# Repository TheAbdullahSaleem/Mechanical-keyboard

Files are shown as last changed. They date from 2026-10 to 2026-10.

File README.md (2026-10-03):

# Mechanical KEEB!!! 
This is a keyboard completely made by me 



## HOW THIS WAS MADE
I made it from scratch compltely scratch and followed the keeb.hackclub guide for it

## How to install:
It is not installable how ever you can see the 3d model at https://cad.onshape.com/documents/bb4cb905776d924b12e08e8f/w/9ffe8c12da04f62d852a73e0/e/dd87c740e253aa3d1df2d833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
or just clone this repo

## FEEDBACK:
Your feedbacks are very valuable for us , message me on slack my handle is @Mewton (I know its funny it is like cat plus newton)

## AI DISCLOSURE
I used ai for some testing and clarity cuz it was my first project like this

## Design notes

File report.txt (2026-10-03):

Info: Processing symbol 'A1:Module:RaspberryPi_Pico_Common_Unspecified'.
Info: Processing symbol 'SW80:PCM_marbastlib-mx:SW_MX_1.75u'.
Info: Processing symbol 'D1:Diode_THT:D_DO-35_SOD27_P7.62mm_Horizontal'.
Info: Processing symbol 'D2:Diode_THT:D_DO-35_SOD27_P7.62mm_Horizontal'.
Info: Processing symbol 'D3:Diode_THT:D_DO-35_SOD27_P7.62mm_Horizontal'.
Info: Processing symbol 'D4:Diode_THT:D_DO-35_SOD27_P7.62mm_Horizontal'.
Info: Processing symbol 'D5:Diode_THT:D_DO-35_SOD27_P7.62mm_Horizontal'.
Info: Processing symbol 'D6:Diode_THT:D_DO-35_SOD27_P7.62mm_Horizontal'.
Info: Processing symbol 'D7:Diode_THT:D_DO-35_SOD27_P7.62mm_Horizontal'.
Info: Processing symbol 'D8:Diode_THT:D_DO-35_SOD27_P7.62mm_Horizontal'.
Info: Processing symbol 'D9:Diode_THT:D_DO-35_SOD27_P7.62mm_Horizontal'.
Info: Processing symbol 'D10:Diode_THT:D_DO-35_SOD27_P7.62mm_Horizontal'.
Info: Processing symbol 'D11:Diode_THT:D_DO-35_SOD27_P7.62mm_Horizontal'.
Info: Processing symbol 'D12:Diode_THT:D_DO-35_SOD27_P7.62mm_Horizontal'.
Info: Processing symbol 'D13:Diode_THT:D_DO-35_SOD27_P7.62mm_Horizontal'.
Info: Processing symbol 'D14:Diode_THT:D_DO-35_SOD27_P7.62mm_Horizontal'.
Info: Processing symbol 'D15:Diode_THT:D_DO-35_SOD27_P7.62mm_Horizontal'.
Info: Processing symbol 'D16:Diode_THT:D_DO-35_SOD27_P7.62mm_Horizontal'.
Info: Processing symbol 'D17:Diode_THT:D_DO-35_SOD27_P7.62mm_Horizontal'.
Info: Processing symbol 'D18:Diode_THT:D_DO-35_SOD27_P7.62mm_Horizontal'.
Info: Processing symbol 'D19:Diode_THT:D_DO-35_SOD27_P7.62mm_Horizontal'.
Info: Processing symbol 'D20:Diode_THT:D_DO-35_SOD27_P7.62mm_Horizontal'.
Info: Processing symbol 'D21:Diode_THT:D_DO-35_SOD27_P7.62mm_Horizontal'.
Info: Processing symbol 'D22:Diode_THT:D_DO-35_SOD27_P7.62mm_Horizontal'.
Info: Processing symbol 'D23:Diode_THT:D_DO-35_SOD27_P7.62mm_Horizontal'.
Info: Processing symbol 'D24:Diode_THT:D_DO-35_SOD27_P7.62mm_Horizontal'.
Info: Processing symbol 'D25:Diode_THT:D_DO-35_SOD27_P7.62mm_Horizontal'.
Info: Processing symbol 'D26:Diode_THT:D_DO-35_SOD27_P7.62mm_Horizontal'.
Info: Processing symbol 'D27:Diode_THT:D_DO-35_SOD27_P7.62mm_Horizontal'.
Info: Processing symbol 'D28:Diode_THT:D_DO-35_SOD27_P7.62mm_Horizontal'.
Info: Processing symbol 'D29:Diode_THT:D_DO-35_SOD27_P7.62mm_Horizontal'.
Info: Processing symbol 'D30:Diode_THT:D_DO-35_SOD27_P7.62mm_Horizontal'.
Info: Processing symbol 'D31:Diode_THT:D_DO-35_SOD27_P7.62mm_Horizontal'.
Info: Processing symbol 'D32:Diode_THT:D_DO-35_SOD27_P7.62mm_Horizontal'.
Info: Processing symbol 'D33:Diode_THT:D_DO-35_SOD27_P7.62mm_Horizontal'.
Info: Processing symbol 'D34:Diode_THT:D_DO-35_SOD27_P7.62mm_Horizontal'.
Info: Processing symbol 'D35:Diode_THT:D_DO-35_SOD27_P7.62mm_Horizontal'.
Info: Processing symbol 'D36:Diode_THT:D_DO-35_SOD27_P7.62mm_Horizontal'.
Info: Processing symbol 'D37:Diode_THT:D_DO-35_SOD27_P7.62mm_Horizontal'.
Info: Processing symbol 'D38:Diode_THT:D_DO-35_SOD27_P7.62mm_Horizontal'.
Info: Processing symbol 'D39:Diode_THT:D_DO-35_SOD27_P7.62mm_Horizontal'.
Info: Processing symbol 'D40:Diode_THT:D_DO-35_SOD27_P7.62mm_Horizontal'.
Info: Processing symbol 'D41:Diode_THT:D_DO-35_SOD27_P7.62mm_Horizontal'.
Info: Processing symbol 'D42:Diode_THT:D_DO-35_SOD27_P7.62mm_Horizontal'.
Info: Processing symbol 'D43:Diode_THT:D_DO-35_SOD27_P7.62mm_Horizontal'.
Info: Processing symbol 'D44:Diode_THT:D_DO-35_SOD27_P7.62mm_Horizontal'.
Info: Processing symbol 'D45:Diode_THT:D_DO-35_SOD27_P7.62mm_Horizontal'.
Info: Processing symbol 'D46:Diode_THT:D_DO-35_SOD27_P7.62mm_Horizontal'.
Info: Processing symbol 'D47:Diode_THT:D_DO-35_SOD27_P7.62mm_Horizontal'.
Info: Processing symbol 'D48:Diode_THT:D_DO-35_SOD27_P7.62mm_Horizontal'.
Info: Processing symbol 'D49:Diode_THT:D_DO-35_SOD27_P7.62mm_Horizontal'.
Info: Processing symbol 'D50:Diode_THT:D_DO-35_SOD27_P7.62mm_Horizontal'.
Info: Processing symbol 'D51:Diode_THT:D_DO-35_SOD27_P7.62mm_Horizontal'.
Info: Processing symbol 'D52:Diode_THT:D_DO-35_SOD27_P7.62mm_Horizontal'.
Info: Processing symbol 'D53:Diode_THT:D_DO-35_SOD27_P7.62mm_Horizontal'.
Info: Processing symbol 'D54:Diode_THT:D_DO-35_SOD27_P7.62mm_Horizontal'.
Info: Processing symbol 'D55:Diode_THT:D_DO-35_SOD27_P7.62mm_Horizontal'.
Info: Processing symbol 'D56:Diode_THT:D_DO-35_SOD27_P7.62mm_Horizontal'.
Info: Processing symbol 'D57:Diode_THT:D_DO-35_SOD27_P7.62mm_Horizontal'.
Info: Processing symbol 'D58:Diode_THT:D_DO-35_SOD27_P7.62mm_Horizontal'.
Info: Processing symbol 'D59:Diode_THT:D_DO-35_SOD27_P7.62mm_Horizontal'.
Info: Processing symbol 'D60:Diode_THT:D_DO-35_SOD27_P7.62mm_Horizontal'.
Info: Processing symbol 'D61:Diode_THT:D_DO-35_SOD27_P7.62mm_Horizontal'.
Info: Processing symbol 'D62:Diode_THT:D_DO-35_SOD27_P7.62mm_Horizontal'.
Info: Processing symbol 'D63:Diode_THT:D_DO-35_SOD27_P7.62mm_Horizontal'.
Info: Processing symbol 'D64:Diode_THT:D_DO-35_SOD27_P7.62mm_Horizontal'.
Info: Processing symbol 'D65:Diode_THT:D_DO-35_SOD27_P7.62mm_Horizontal'.
Info: Processing symbol 'D66:Diode_THT:D_DO-35_SOD27_P7.62mm_Horizontal'.
Info: Processing symbol 'D67:Diode_THT:D_DO-35_SOD27_P7.62mm_Horizontal'.
Info: Processing symbol 'D68:Diode_THT:D_DO-35_SOD27_P7.62mm_Horizontal'.
Info: Processing symbol 'D69:Diode_THT:D_DO-35_SOD27_P7.62mm_Horizontal'.
Info: Processing symbol 'D70:Diode_THT:D_DO-35_SOD27_P7.62mm_Horizontal'.
Info: Processing symbol 'D71:Diode_THT:D_DO-35_SOD27_P7.62mm_Horizontal'.
Info: Processing symbol 'D72:Diode_THT:D_DO-35_SOD27_P7.62mm_Horizontal'.
Info: Processing symbol 'D73:Diode_THT:D_DO-35_SOD27_P7.62mm_Horizontal'.
Info: Processing symbol 'D74:Diode_THT:D_DO-35_SOD27_P7.62mm_Horizontal'.
Info: Processing symbol 'D75:Diode_THT:D_DO-35_SOD27_P7.62mm_Horizontal'.
Info: Processing symbol 'D76:Diode_THT:D_DO-35_SOD27_P7.62mm_Horizontal'.
Info: Processing symbol 'D77:Diode_THT:D_DO-35_SOD27_P7.62mm_Horizontal'.
Info: Processing symbol 'D78:Diode_THT:D_DO-35_SOD27_P7.62mm_Horizontal'.
Info: Processing symbol 'D79:Diode_THT:D_DO-35_SOD27_P7.62mm_Horizontal'.
Info: Processing symbol 'D80:Diode_THT:D_DO-35_SOD27_P7.62mm_Horizontal'.
Info: Processing symbol 'D81:Diode_THT:D_DO-35_SOD27_P7.62mm_Horizontal'.
Info: Processing symbol 'D82:Diode_THT:D_DO-35_SOD27_P7.62mm_Horizontal'.
Info: Processing symbol 'D83:Diode_THT:D_DO-35_SOD27_P7.62mm_Horizontal'.
Info: Processing symbol 'D84:Diode_THT:D_DO-35_SOD27_P7.62mm_Horizontal'.
Info: Processing symbol 'H1:MountingHole:MountingHole_2.2mm_M2_Pad'.
Info: Processing symbol 'SW81:PCM_marbastlib-mx:SW_MX_1.5u'.
Info: Processing symbol 'H2:MountingHole:MountingHole_2.2mm_M2_Pad'.
Info: Processing symbol 'SW82:PCM_marbastlib-mx:SW_MX_1.5u'.
Info: Processing symbol 'H3:MountingHole:MountingHole_2.2mm_M2_Pad'.
Info: Processing symbol 'SW83:PCM_marbastlib-mx:SW_MX_1.25u'.
Info: Processing symbol 'H4:MountingHole:MountingHole_2.2mm_M2_Pad'.
Info: Processing symbol 'SW84:PCM_marbastlib-mx:SW_MX_1.25u'.
Info: Processing symbol 'H5:MountingHole:MountingHole_2.2mm_M2_Pad'.
Info: Processing symbol 'SW85:PCM_marbastlib-mx:SW_MX_1.25u'.
Info: Processing symbol 'H6:MountingHole:MountingHole_2.2mm_M2_Pad'.
Info: Processing symbol 'U2:Display:ER_OLEDM0.91_1x-I2C'.
Info: Processing symbol 'H7:MountingHole:MountingHole_2.2mm_M2_Pad'.
Info: Processing symbol 'H8:MountingHole:MountingHole_2.2mm_M2_Pad'.
Info: Processing symbol 'R1:Resistor_SMD:R_0805_2012Metric_Pad1.20x1.40mm_HandSolder'.
Info: Processing symbol 'R2:Resistor_SMD:R_0805_2012Metric_Pad1.20x1.40mm_HandSolder'.
Info: Processing symbol 'S1:PCM_marbastlib-mx:STAB_MX_P_6.25u'.
Info: Processing symbol 'S2:PCM_marbastlib-mx:STAB_MX_P_2.25u'.
Info: Processing symbol 'S3:PCM_marbastlib-mx:STAB_MX_P_2.25u'.
Info: Processing symbol 'S4:PCM_marbastlib-mx:STAB_MX_P_2u'.
Info: Processing symbol 'SW1:Rotary_Encoder:RotaryEncoder_Alps_EC11E-Switch_Vertical_H20mm'.
Info: Processing symbol 'SW2:PCM_marbastlib-mx:SW_MX_1u'.
Info: Processing symbol 'SW3:PCM_marbastlib-mx:SW_MX_1u'.
Info: Processing symbol 'SW4:PCM_marbastlib-mx:SW_MX_1u'.
Info: Processing symbol 'SW5:PCM_marbastlib-mx:SW_MX_1u'.
Info: Processing symbol 'SW6:PCM_marbastlib-mx:SW_MX_1u'.
Info: Processing symbol 'SW7:PCM_marbastlib-mx:SW_MX_1u'.
Info: Processing symbol 'SW8:PCM_marbastlib-mx:SW_MX_1u'.
Info: Processing symbol 'SW9:PCM_marbastlib-mx:SW_MX_1u'.
Info: Processing symbol 'SW10:PCM_marbastlib-mx:SW_MX_1u'.
Info: Processing symbol 'SW11:PCM_marbastlib-mx:SW_MX_1u'.
Info: Processing symbol 'SW12:PCM_marbastlib-mx:SW_MX_1u'.
Info: Processing symbol 'SW13:PCM_marbastlib-mx:SW_MX_1u'.
Info: Processing symbol 'SW14:PCM_marbastlib-mx:SW_MX_1u'.
Info: Processing symbol 'SW15:PCM_marbastlib-mx:SW_MX_1u'.
Info: Processing symbol 'SW16:PCM_marbastlib-mx:SW_MX_1u'.
Info: Processing symbol 'SW17:PCM_marbastlib-mx:SW_MX_1u'.
Info: Processing symbol 'SW18:PCM_marbastlib-mx:SW_MX_1u'.
Info: Processing symbol 'SW19:PCM_marbastlib-mx:SW_MX_1u'.
Info: Processing symbol 'SW20:PCM_marbastlib-mx:SW_MX_1u'.
Info: Processing symbol 'SW21:PCM_marbastlib-mx:SW_MX_1u'.
Info: Processing symbol 'SW22:PCM_marbastlib-mx:SW_MX_1u'.
Info: Processing symbol 'SW23:PCM_marbastlib-mx:SW_MX_1u'.
Info: Processing symbol 'SW24:PCM_marbastlib-mx:SW_MX_1u'.
Info: Processing symbol 'SW25:PCM_marbastlib-mx:SW_MX_1u'.
Info: Processing symbol 'SW26:PCM_marbastlib-mx:SW_MX_1u'.
Info: Processing symbol 'SW27:PCM_marbastlib-mx:SW_MX_1u'.
Info: Processing symbol 'SW28:PCM_marbastlib-mx:SW_MX_1u'.
Info: Processing symbol 'SW29:PCM_marbastlib-mx:SW_MX_1u'.
Info: Processing symbol 'SW30:PCM_marbastlib-mx:SW_MX_1u'.
Info: Processing symbol 'SW31:PCM_marbastlib-mx:SW_MX_1u'.
Info: Processing symbol 'SW32:PCM_marbastlib-mx:SW_MX_1u'.
Info: Processing symbol 'SW33:PCM_marbastlib-mx:SW_MX_1u'.
Info: Processing symbol 'SW34:PCM_marbastlib-mx:SW_MX_1u'.
Info: Processing symbol 'SW35:PCM_marbastlib-mx:SW_MX_1u'.
Info: Processing symbol 'SW36:PCM_marbastlib-mx:SW_MX_1u'.
Info: Processing symbol 'SW37:PCM_marbastlib-mx:SW_MX_1u'.
Info: Processing symbol 'SW38:PCM_marbastlib-mx:SW_MX_1u'.
Info: Processing symbol 'SW39:PCM_marbastlib-mx:SW_MX_1u'.
Info: Processing symbol 'SW40:PCM_marbastlib-mx:SW_MX_1u'.
Info: Processing symbol 'SW41:PCM_marbastlib-mx:SW_MX_1u'.
Info: Processing symbol 'SW42:PCM_marbastlib-mx:SW_MX_1u'.
Info: Processing symbol 'SW43:PCM_marbastlib-mx:SW_MX_1u'.
Info: Processing symbol 'SW44:PCM_marbastlib-mx:SW_MX_1u'.
Info: Processing symbol 'SW45:PCM_marbastlib-mx:SW_MX_1u'.
Info: Processing symbol 'SW46:PCM_marbastlib-mx:SW_MX_1u'.
Info: Processing symbol 'SW47:PCM_marbastlib-mx:SW_MX_1u'.
Info: Processing symbol 'SW48:Button_Switch_Keyboard:SW_Cherry_MX_2.25u_Plate'.
Info: Processing symbol 'SW49:PCM_marbastlib-mx:SW_MX_1u'.
Info: Processing symbol 'SW50:PCM_marbastlib-mx:SW_MX_1u'.
Info: Processing symbol 'SW51:PCM_marbastlib-mx:SW_MX_1u'.
Info: Processing symbol 'SW52:PCM_marbastlib-mx:SW_MX_1u'.
Info: Processing symbol 'SW53:PCM_marbastlib-mx:SW_MX_1u'.
Info: Processing symbol 'SW54:PCM_marbastlib-mx:SW_MX_1u'.
Info: Processing symbol 'SW55:PCM_marbastlib-mx:SW_MX_1u'.
Info: Processing symbol 'SW56:PCM_marbastlib-mx:SW_MX_1u'.
Info: Processing symbol 'SW57:PCM_marbastlib-mx:SW_MX_1u'.
Info: Processing symbol 'SW58:PCM_marbastlib-mx:SW_MX_1u'.
Info: Processing symbol 'SW59:PCM_marbastlib-mx:SW_MX_1u'.
Info: Processing symbol 'SW60:PCM_marbastlib-mx:SW_MX_1u'.
Info: Processing symbol 'SW61:PCM_marbastlib-mx:SW_MX_1u'.
Info: Processing symbol 'SW62:PCM_marbastlib-mx:SW_MX_1u'.
Info: Processing symbol 'SW63:PCM_marbastlib-mx:SW_MX_1u'.
Info: Processing symbol 'SW64:PCM_marbastlib-mx:SW_MX_1u'.
Info: Processing symbol 'SW65:PCM_marbastlib-mx:SW_MX_1u'.
Info: Processing symbol 'SW66:PCM_marbastlib-mx:SW_MX_1u'.
Info: Processing symbol 'SW67:PCM_marbastlib-mx:SW_MX_1u'.
Info: Processing symbol 'SW68:PCM_marbastlib-mx:SW_MX_1u'.
Info: Processing symbol 'SW69:PCM_marbastlib-mx:SW_MX_1u'.
Info: Processing symbol 'SW70:PCM_marbastlib-mx:SW_MX_1u'.
Info: Processing symbol 'SW71:PCM_marbastlib-mx:SW_MX_1u'.
Info: Processing symbol 'SW72:PCM_marbastlib-mx:SW_MX_1u'.
Info: Processing symbol 'SW73:PCM_marbastlib-mx:SW_MX_1u'.
Info: Processing symbol 'SW74:PCM_marbastlib-mx:SW_MX_1u'.
Info: Processing symbol 'SW75:PCM_marbastlib-mx:SW_MX_1u'.
Info: Processing symbol 'SW76:Button_Switch_Keyboard:SW_Cherry_MX_6.25u_Plate'.
Info: Processing symbol 'SW77:Button_Switch_Keyboard:SW_Cherry_MX_2.25u_Plate'.
Info: Processing symbol 'SW78:Button_Switch_Keyboard:SW_Cherry_MX_2.00u_Plate'.
Info: Processing symbol 'SW79:PCM_marbastlib-mx:SW_MX_1.75u'.
Add A1 (footprint 'Module:RaspberryPi_Pico_Common_Unspecified').
Add SW75 (footprint 'PCM_marbastlib-mx:SW_MX_1u').
Warning: No net found for component H1 pad 1 (no pin 1 in symbol).
Warning: No net found for component H2 pad 1 (no pin 1 in symbol).
Warning: No net found for component H3 pad 1 (no pin 1 in symbol).
Warning: No net found for component H4 pad 1 (no pin 1 in symbol).
Warning: No net found for component H5 pad 1 (no pin 1 in symbol).
Warning: No net found for component H6 pad 1 (no pin 1 in symbol).
Warning: No net found for component SW1 pad MP (no pin MP in symbol).
Warning: No net found for component H8 pad 1 (no pin 1 in symbol).
Warning: No net found for component H7 pad 1 (no pin 1 in symbol).
Warning: No net found for component SW1 pad MP (no pin MP in symbol).

Info: Total warnings: 10, errors: 0.

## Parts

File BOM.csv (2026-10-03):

Component Name | Quantity | Total Price
Gateron G Pro 2.0 Yellow Switch Set | 100 | 42.15$
Glorious PBT Key Caps For Gaming Keyboard - Arctic White | 1 Complete set | 23.06$
Durock V2 Stabilizers Screw-In | Complete Set | 20$
RP2040 Microcontroller Development Board with Type-C USB | 1 | 13$
Diodes (1N4148) (through holes) | 100 | 3.60$
RGB lights for keys | 1 | 10$
OLED screen | 1 | 3$

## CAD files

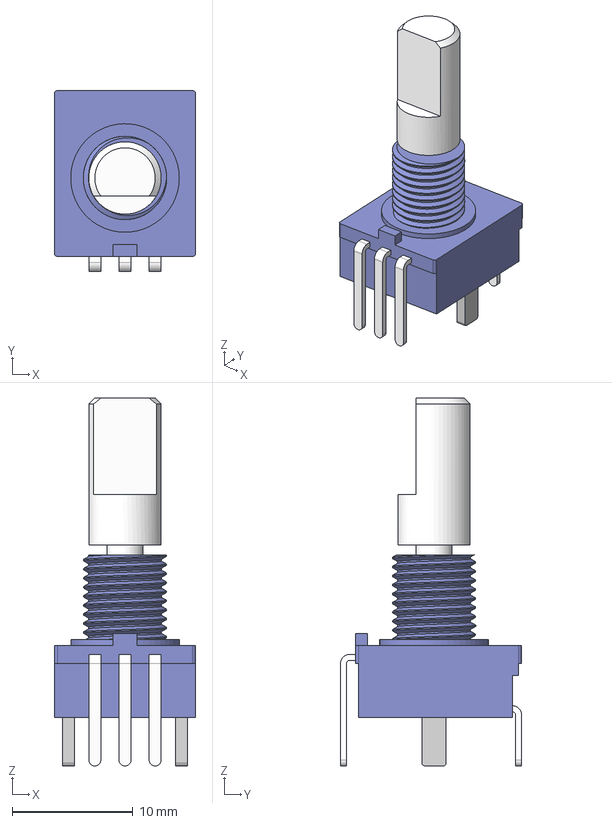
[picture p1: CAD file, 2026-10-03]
assets/CUI_ACZ11BR2E-20FD1.step
11.7 x 15.0 x 30.5 mm
Shaft
Pins

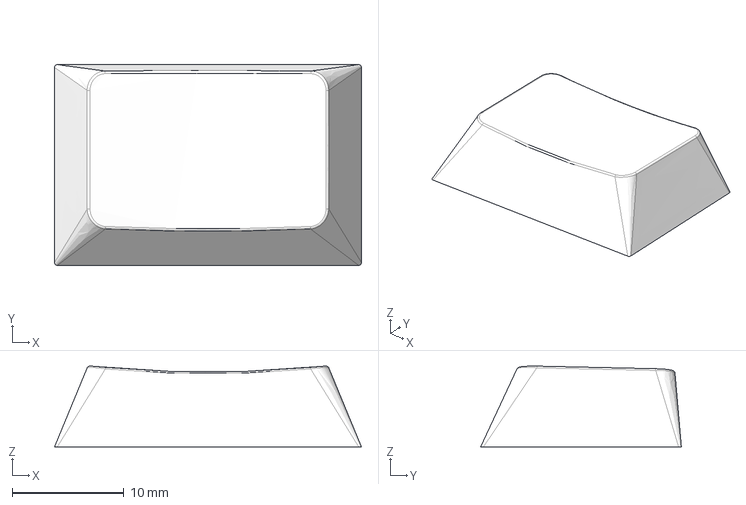
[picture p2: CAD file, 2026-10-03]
assets/KEYCAPS/1.5_r2.step
27.5 x 18.0 x 7.25 mm

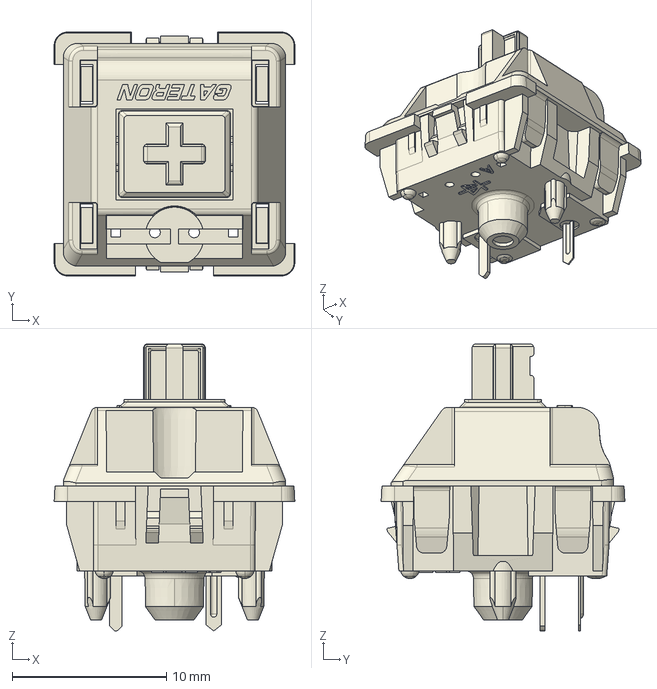
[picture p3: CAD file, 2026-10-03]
assets/KS-8SwitchKS-8-X5/KS-8 Switch KS-8-X5.stp
15.6 x 15.8 x 18.6 mm

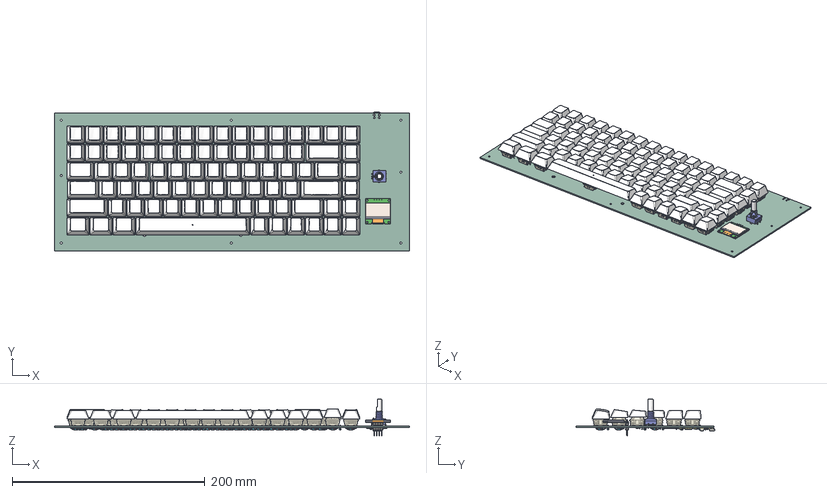
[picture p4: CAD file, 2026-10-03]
My Mechanical Keyboard.step
368.5 x 143.8 x 38.0 mm
RD-05C786B9Fyifh x 84
Product010 x 30
Product007 x 12
Product026
Product009 x 13
Product002
Product006 x 6
Product008 x 12
Product030 x 3
Product039
Product034 x 2
Product038
Product025
Product024
D_DO-35_SOD27_P7.62mm_Horizontal x 84
R_0805_2012Metric x 2
RaspberryPi_Pico_Module_KiCad
PinHeader_1x04_P254mm_Vertical
brep_2 x 4
Shaft
Pins
My 3F9F_PCB

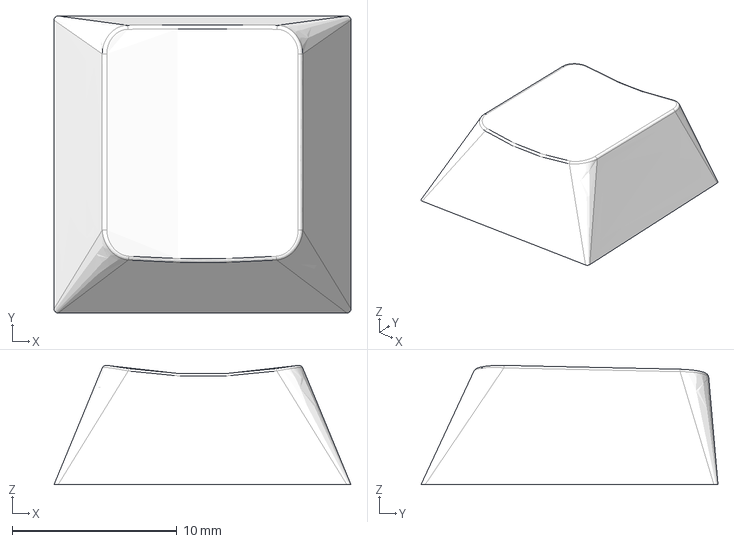
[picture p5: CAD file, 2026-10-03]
assets/KEYCAPS/1u_r2.step
18.0 x 18.0 x 7.23 mm

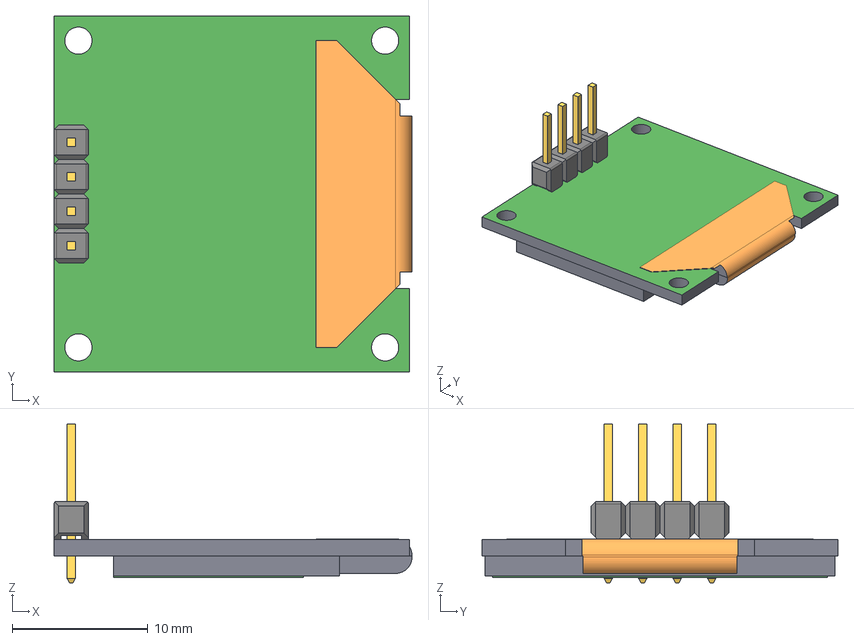
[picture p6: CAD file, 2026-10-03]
assets/OLED TEMU 0.96 in.stp
26.4 x 26.2 x 11.7 mm
brep_2 x 4

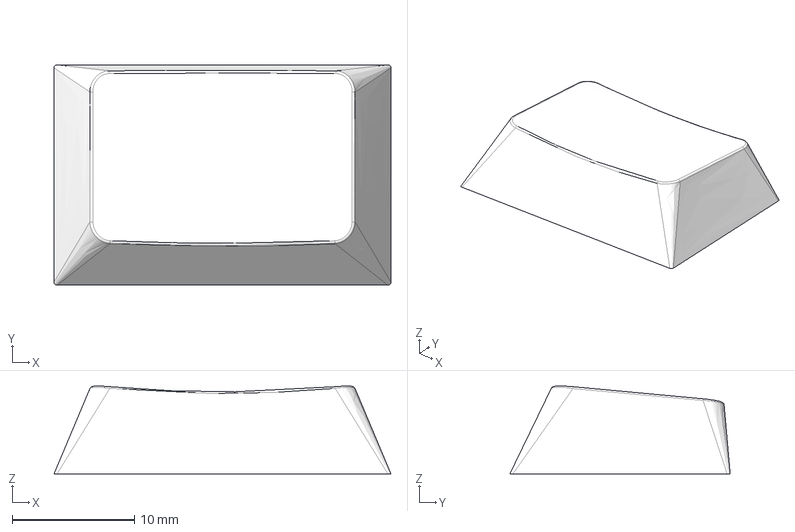
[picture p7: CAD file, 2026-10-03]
assets/KEYCAPS/1.5u_r3.step
27.5 x 18.0 x 7.18 mm

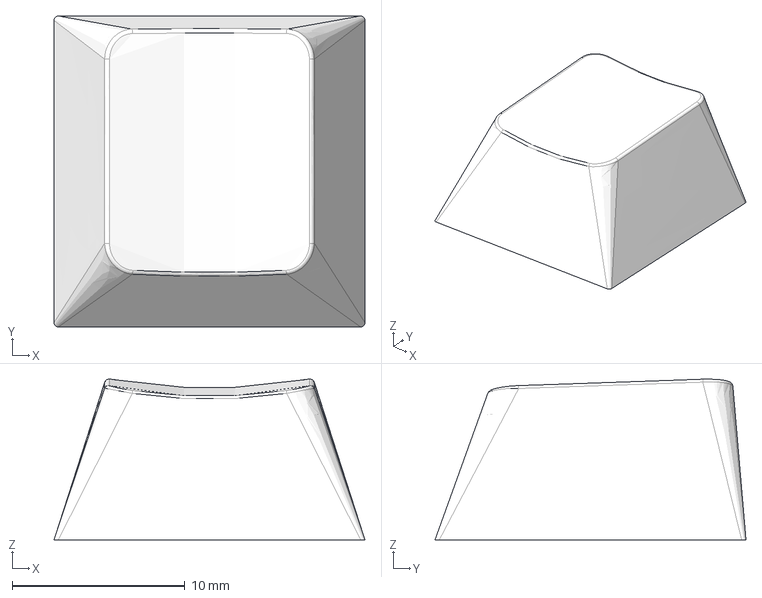
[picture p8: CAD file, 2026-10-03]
assets/KEYCAPS/1u_r1.step
18.0 x 18.0 x 9.30 mm

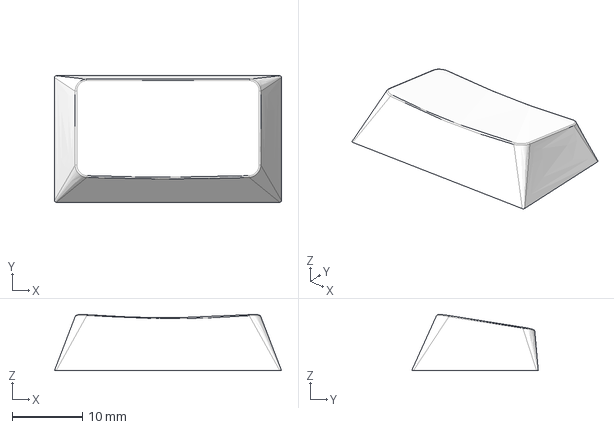
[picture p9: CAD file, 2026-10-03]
assets/KEYCAPS/1.75u_r4.step
32.3 x 18.0 x 7.97 mm

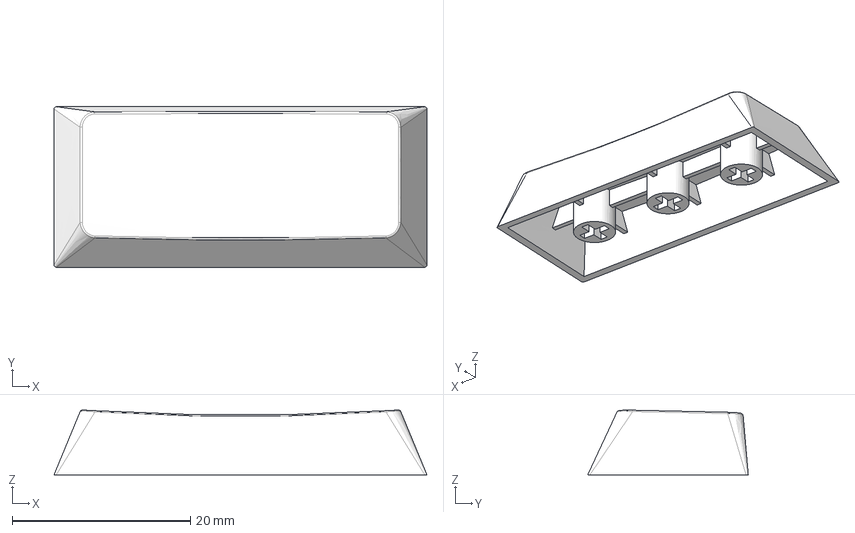
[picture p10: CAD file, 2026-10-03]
assets/KEYCAPS/2.25u_r2.step
41.8 x 18.0 x 7.26 mm

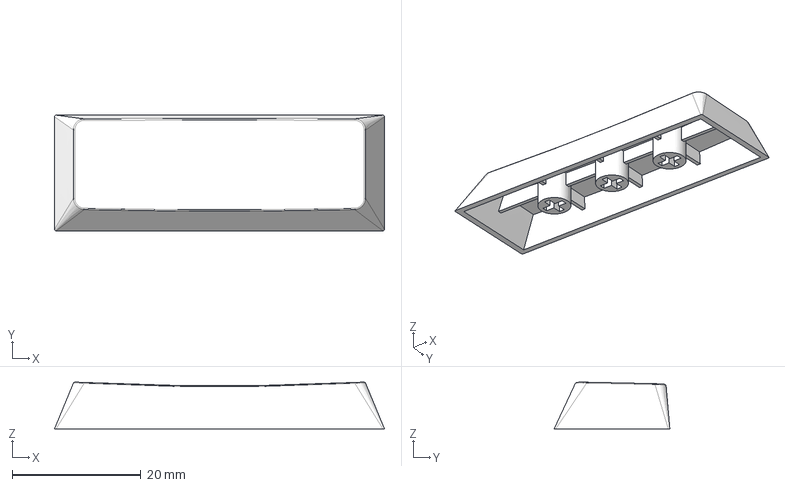
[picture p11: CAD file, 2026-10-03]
assets/KEYCAPS/2.75u_r2.step
51.3 x 18.0 x 7.26 mm

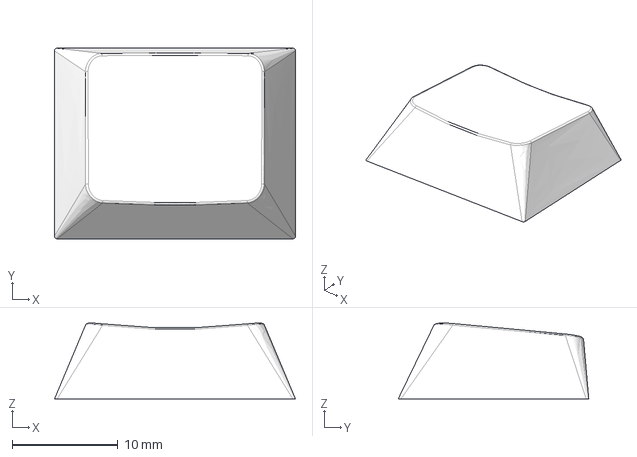
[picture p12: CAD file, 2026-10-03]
assets/KEYCAPS/1.25u_r3.step
22.8 x 18.0 x 7.17 mm

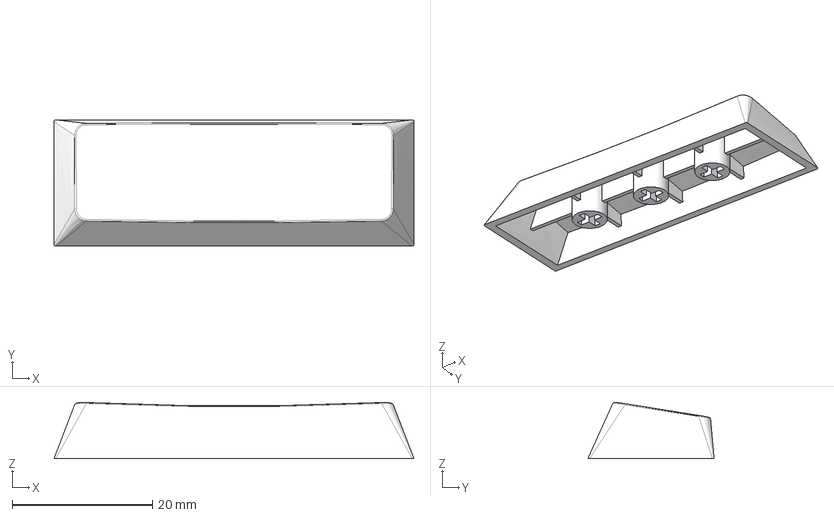
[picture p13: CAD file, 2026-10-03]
assets/KEYCAPS/2.75u_r4.step
51.3 x 18.0 x 8.00 mm

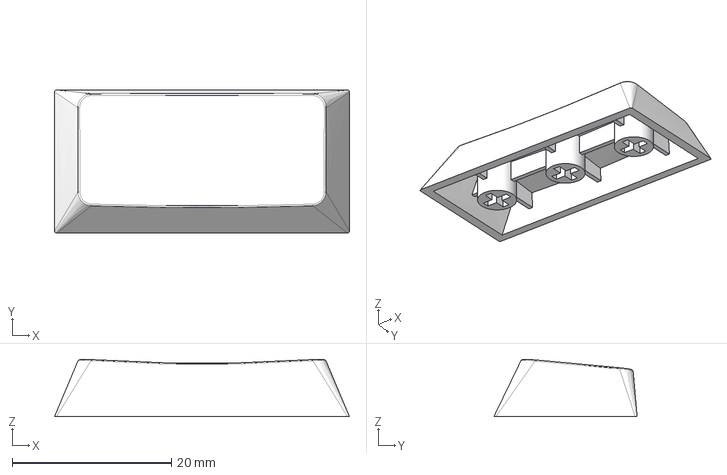
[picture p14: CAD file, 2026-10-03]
assets/KEYCAPS/2u_r3.step
37.1 x 18.0 x 7.20 mm

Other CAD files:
assets/KEYCAPS/2u_r2.step
assets/KEYCAPS/Unnamed1-Product047Product033.step
assets/KEYCAPS/1.5u_r1.step
assets/KEYCAPS/2.75u_sb.step
assets/KEYCAPS/1.25_r1.step
assets/KEYCAPS/1.25u_r2.step
assets/KEYCAPS/1.25u_r4.step
assets/KEYCAPS/1.25u_sb.step
assets/KEYCAPS/1.5u_r4.step
assets/KEYCAPS/1.5u_sb.step
assets/KEYCAPS/1.75u_r1.step
assets/KEYCAPS/1.75u_r2.step
assets/KEYCAPS/1.75u_r3.step
assets/KEYCAPS/1.75u_sb.step
assets/KEYCAPS/1u_r3.step
assets/KEYCAPS/1u_r4.step
assets/KEYCAPS/1u_sb.step
assets/KEYCAPS/2.25u_r1.step
assets/KEYCAPS/2.25u_r3.step
assets/KEYCAPS/2.25u_r4.step
assets/KEYCAPS/2.25u_sb.step
assets/KEYCAPS/2.5u_r1.step
assets/KEYCAPS/2.5u_r2.step
assets/KEYCAPS/2.5u_r3.step
assets/KEYCAPS/2.5u_r4.step
assets/KEYCAPS/2.5u_sb.step
assets/KEYCAPS/2.75u_r1.step
assets/KEYCAPS/2.75u_r3.step
assets/KEYCAPS/2u_r1.step
assets/KEYCAPS/2u_r4.step
assets/KEYCAPS/2u_sb.step
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

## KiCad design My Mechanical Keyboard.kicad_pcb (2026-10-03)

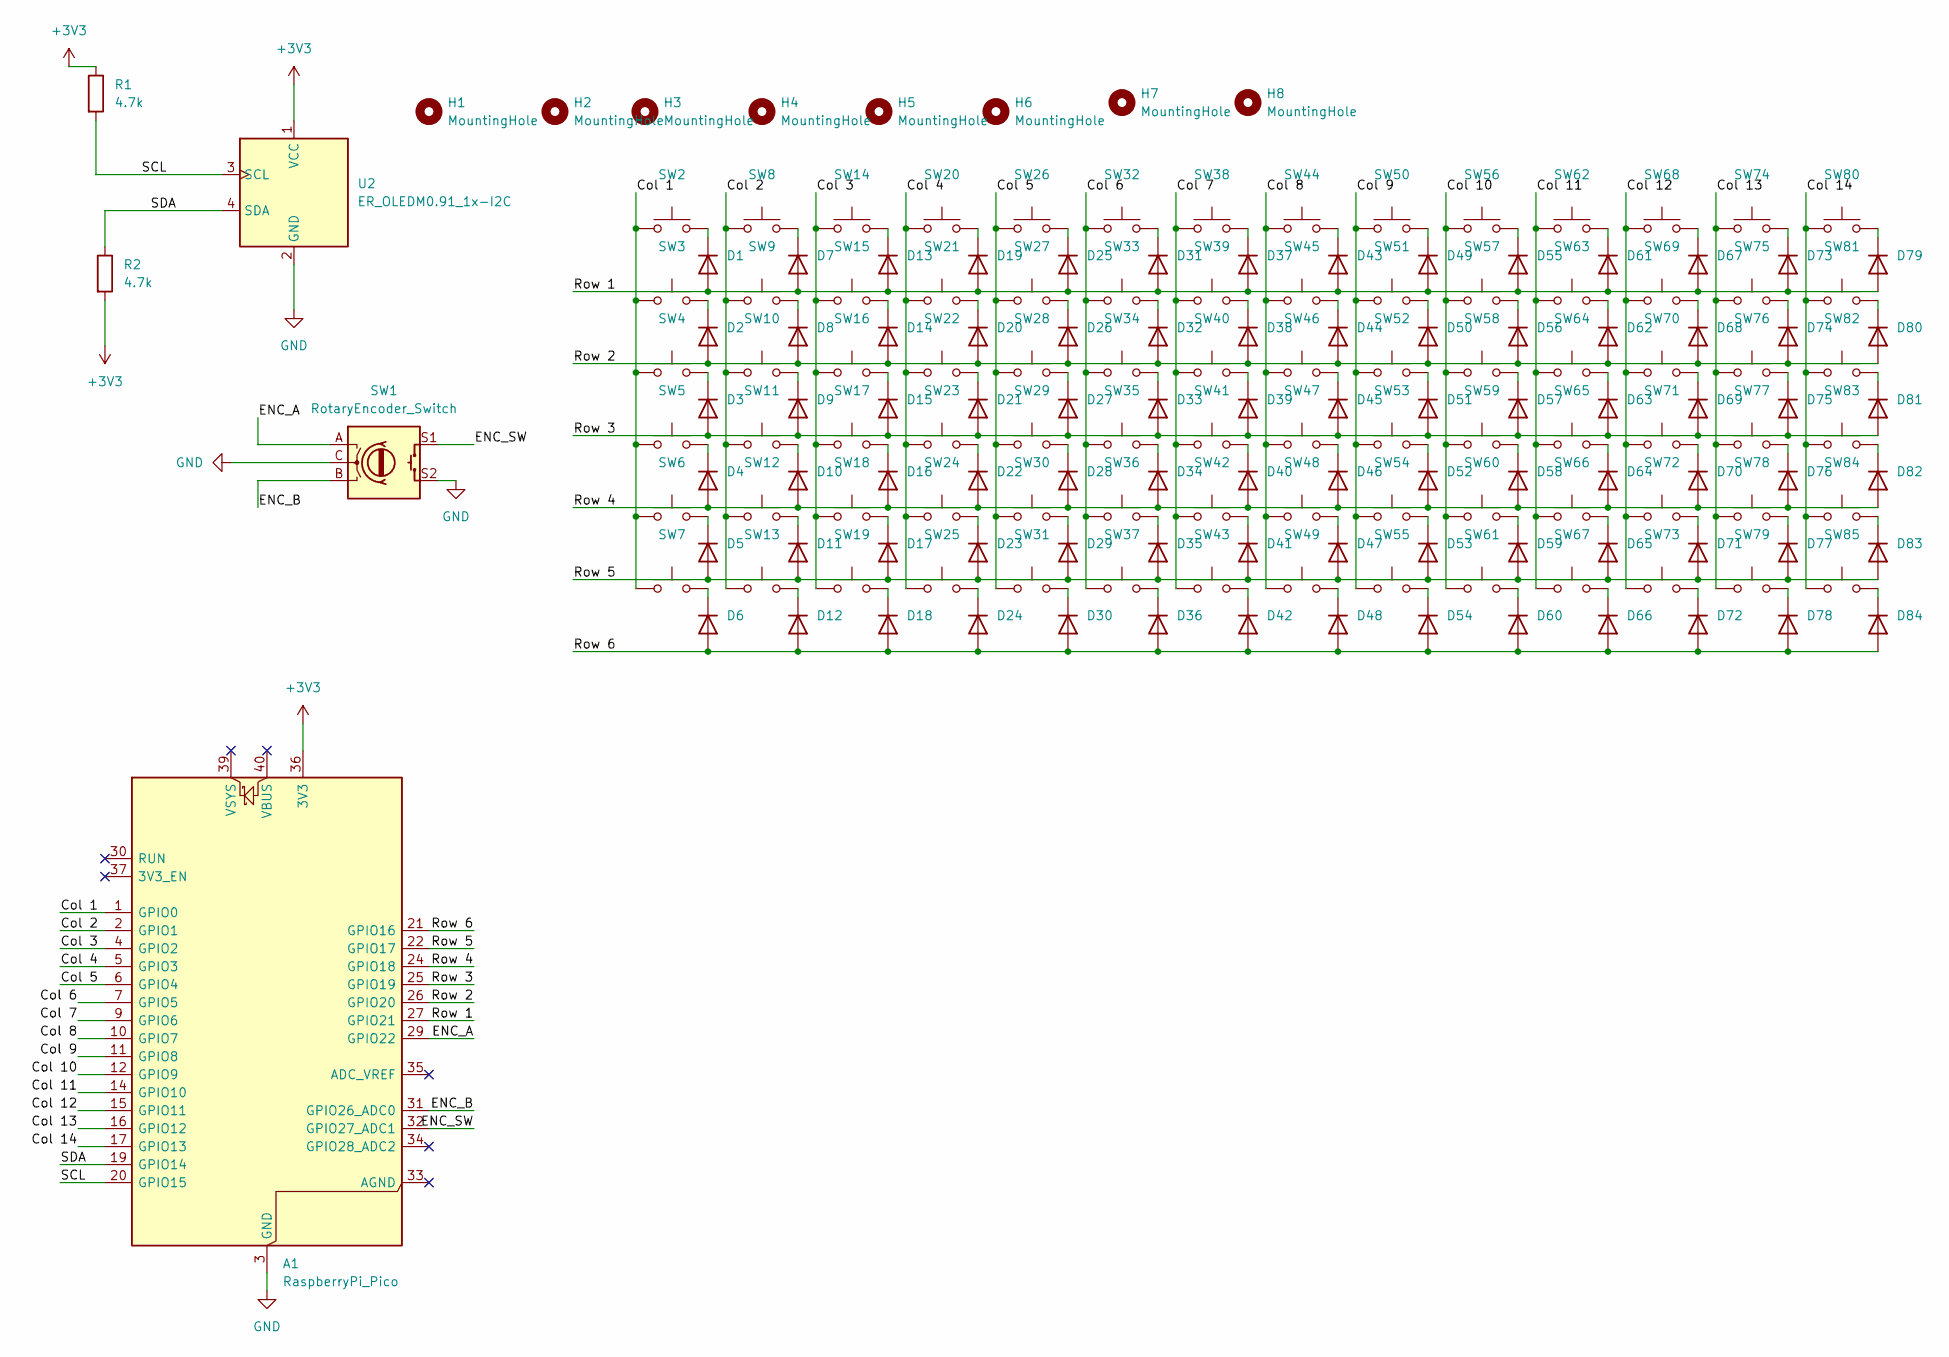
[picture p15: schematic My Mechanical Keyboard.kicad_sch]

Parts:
A1: RaspberryPi_Pico; RaspberryPi_Pico_Common_SMD
D1, D2, D3, D4, D5, D6, D7, D8, D9, D10, D11, D12, D13, D14, D15, D16, D17, D18, D19, D20, D21, D22, D23, D24, D25, D26, D27, D28, D29, D30, D31, D32, D33, D34, D35, D36, D37, D38, D39, D40, D41, D42, D43, D44, D45, D46, D47, D48, D49, D50, D51, D52, D53, D54, D55, D56, D57, D58, D59, D60, D61, D62, D63, D64, D65, D66, D67, D68, D69, D70, D71, D72, D73, D74, D75, D76, D77, D78, D79, D80, D81, D82, D83, D84: 1N4148; D_DO-35_SOD27_P7.62mm_Horizontal
H1, H2, H3, H4, H5, H6, H7, H8: MountingHole; MountingHole_2.2mm_M2_Pad
R1, R2: 4.7k; R_0805_2012Metric_Pad1.20x1.40mm_HandSolder
SW1: RotaryEncoder_Switch; RotaryEncoder_Alps_EC11E-Switch_Vertical_H20mm
SW2, SW3, SW8, SW9, SW10, SW11, SW12, SW14, SW15, SW16, SW17, SW18, SW20, SW21, SW22, SW23, SW24, SW26, SW27, SW28, SW29, SW30, SW31, SW32, SW33, SW34, SW35, SW36, SW37, SW38, SW39, SW40, SW41, SW42, SW43, SW44, SW45, SW46, SW47, SW48, SW49, SW50, SW51, SW52, SW53, SW54, SW55, SW56, SW57, SW58, SW59, SW60, SW61, SW62, SW63, SW64, SW65, SW67, SW68, SW69, SW70, SW72, SW73, SW74, SW75, SW78, SW79, SW80, SW81, SW82, SW83, SW84, SW85: SW_Push; SW_MX_1u
SW4, SW77: SW_Push; SW_MX_1.5u
SW5, SW66: SW_Push; SW_MX_1.75u
SW6, SW71: SW_Push; SW_Cherry_MX_2.25u_PCB
SW7, SW13, SW19: SW_Push; SW_MX_1.25u
SW25: SW_Push; SW_Cherry_MX_6.25u_PCB
SW76: SW_Push; SW_Cherry_MX_2.00u_PCB
U2: ER_OLEDM0.91_1x-I2C; PinHeader_1x04_P2.54mm_Vertical

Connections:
+3V3: A1.36 (3V3), R1.1, R2.2, U2.1 (VCC)
/Col 1: A1.1 (GPIO0), SW2.1, SW3.1, SW4.1, SW5.1, SW6.1, SW7.1
/Col 2: A1.2 (GPIO1), SW8.1, SW9.1, SW10.1, SW11.1, SW12.1, SW13.1
/Col 3: A1.4 (GPIO2), SW14.1, SW15.1, SW16.1, SW17.1, SW18.1, SW19.1
/Col 4: A1.5 (GPIO3), SW20.1, SW21.1, SW22.1, SW23.1, SW24.1, SW25.1
/Col 5: A1.6 (GPIO4), SW26.1, SW27.1, SW28.1, SW29.1, SW30.1, SW31.1
/Col 6: A1.7 (GPIO5), SW32.1, SW33.1, SW34.1, SW35.1, SW36.1, SW37.1
/Col 7: A1.9 (GPIO6), SW38.1, SW39.1, SW40.1, SW41.1, SW42.1, SW43.1
/Col 8: A1.10 (GPIO7), SW44.1, SW45.1, SW46.1, SW47.1, SW48.1, SW49.1
/Col 9: A1.11 (GPIO8), SW50.1, SW51.1, SW52.1, SW53.1, SW54.1, SW55.1
/Col 10: A1.12 (GPIO9), SW56.1, SW57.1, SW58.1, SW59.1, SW60.1, SW61.1
/Col 11: A1.14 (GPIO10), SW62.1, SW63.1, SW64.1, SW65.1, SW66.1, SW67.1
/Col 12: A1.15 (GPIO11), SW68.1, SW69.1, SW70.1, SW71.1, SW72.1, SW73.1
/Col 13: A1.16 (GPIO12), SW74.1, SW75.1, SW76.1, SW77.1, SW78.1, SW79.1
/Col 14: A1.17 (GPIO13), SW80.1, SW81.1, SW82.1, SW83.1, SW84.1, SW85.1
/ENC_A: A1.29 (GPIO22), SW1.A
/ENC_B: A1.31 (GPIO26_ADC0), SW1.B
/ENC_SW: A1.32 (GPIO27_ADC1), SW1.S1
/Row 1: A1.27 (GPIO21), D1.2 (A), D7.2 (A), D13.2 (A), D19.2 (A), D25.2 (A), D31.2 (A), D37.2 (A), D43.2 (A), D49.2 (A), D55.2 (A), D61.2 (A), D67.2 (A), D73.2 (A), D79.2 (A)
/Row 2: A1.26 (GPIO20), D2.2 (A), D8.2 (A), D14.2 (A), D20.2 (A), D26.2 (A), D32.2 (A), D38.2 (A), D44.2 (A), D50.2 (A), D56.2 (A), D62.2 (A), D68.2 (A), D74.2 (A), D80.2 (A)
/Row 3: A1.25 (GPIO19), D3.2 (A), D9.2 (A), D15.2 (A), D21.2 (A), D27.2 (A), D33.2 (A), D39.2 (A), D45.2 (A), D51.2 (A), D57.2 (A), D63.2 (A), D69.2 (A), D75.2 (A), D81.2 (A)
/Row 4: A1.24 (GPIO18), D4.2 (A), D10.2 (A), D16.2 (A), D22.2 (A), D28.2 (A), D34.2 (A), D40.2 (A), D46.2 (A), D52.2 (A), D58.2 (A), D64.2 (A), D70.2 (A), D76.2 (A), D82.2 (A)
/Row 5: A1.22 (GPIO17), D5.2 (A), D11.2 (A), D17.2 (A), D23.2 (A), D29.2 (A), D35.2 (A), D41.2 (A), D47.2 (A), D53.2 (A), D59.2 (A), D65.2 (A), D71.2 (A), D77.2 (A), D83.2 (A)
/Row 6: A1.21 (GPIO16), D6.2 (A), D12.2 (A), D18.2 (A), D24.2 (A), D30.2 (A), D36.2 (A), D42.2 (A), D48.2 (A), D54.2 (A), D60.2 (A), D66.2 (A), D72.2 (A), D78.2 (A), D84.2 (A)
/SCL: A1.20 (GPIO15), R1.2, U2.3 (SCL)
/SDA: A1.19 (GPIO14), R2.1, U2.4 (SDA)
GND: A1.3 (GND), A1.8 (GND), A1.13 (GND), A1.18 (GND), A1.23 (GND), A1.28 (GND), A1.38 (GND), SW1.C, SW1.S2, U2.2 (GND)
unnamed: D1.1 (K), SW2.2
unnamed: D2.1 (K), SW3.2
unnamed: D3.1 (K), SW4.2
unnamed: D4.1 (K), SW5.2
unnamed: D5.1 (K), SW6.2
unnamed: D6.1 (K), SW7.2
unnamed: D7.1 (K), SW8.2
unnamed: D8.1 (K), SW9.2
unnamed: D9.1 (K), SW10.2
unnamed: D10.1 (K), SW11.2
unnamed: D11.1 (K), SW12.2
unnamed: D12.1 (K), SW13.2
unnamed: D13.1 (K), SW14.2
unnamed: D14.1 (K), SW15.2
unnamed: D15.1 (K), SW16.2
unnamed: D16.1 (K), SW17.2
unnamed: D17.1 (K), SW18.2
unnamed: D18.1 (K), SW19.2
unnamed: D19.1 (K), SW20.2
unnamed: D20.1 (K), SW21.2
unnamed: D21.1 (K), SW22.2
unnamed: D22.1 (K), SW23.2
unnamed: D23.1 (K), SW24.2
unnamed: D24.1 (K), SW25.2
unnamed: D25.1 (K), SW26.2
unnamed: D26.1 (K), SW27.2
unnamed: D27.1 (K), SW28.2
unnamed: D28.1 (K), SW29.2
unnamed: D29.1 (K), SW30.2
unnamed: D30.1 (K), SW31.2
unnamed: D31.1 (K), SW32.2
unnamed: D32.1 (K), SW33.2
unnamed: D33.1 (K), SW34.2
unnamed: D34.1 (K), SW35.2
unnamed: D35.1 (K), SW36.2
unnamed: D36.1 (K), SW37.2
unnamed: D37.1 (K), SW38.2
unnamed: D38.1 (K), SW39.2
unnamed: D39.1 (K), SW40.2
unnamed: D40.1 (K), SW41.2
unnamed: D41.1 (K), SW42.2
unnamed: D42.1 (K), SW43.2
unnamed: D43.1 (K), SW44.2
unnamed: D44.1 (K), SW45.2
unnamed: D45.1 (K), SW46.2
unnamed: D46.1 (K), SW47.2
unnamed: D47.1 (K), SW48.2
unnamed: D48.1 (K), SW49.2
unnamed: D49.1 (K), SW50.2
unnamed: D50.1 (K), SW51.2
unnamed: D51.1 (K), SW52.2
unnamed: D52.1 (K), SW53.2
unnamed: D53.1 (K), SW54.2
unnamed: D54.1 (K), SW55.2
unnamed: D55.1 (K), SW56.2
unnamed: D56.1 (K), SW57.2
unnamed: D57.1 (K), SW58.2
unnamed: D58.1 (K), SW59.2
unnamed: D59.1 (K), SW60.2
unnamed: D60.1 (K), SW61.2
unnamed: D61.1 (K), SW62.2
unnamed: D62.1 (K), SW63.2
unnamed: D63.1 (K), SW64.2
unnamed: D64.1 (K), SW65.2
unnamed: D65.1 (K), SW66.2
unnamed: D66.1 (K), SW67.2
unnamed: D67.1 (K), SW68.2
unnamed: D68.1 (K), SW69.2
unnamed: D69.1 (K), SW70.2
unnamed: D70.1 (K), SW71.2
unnamed: D71.1 (K), SW72.2
unnamed: D72.1 (K), SW73.2
unnamed: D73.1 (K), SW74.2
unnamed: D74.1 (K), SW75.2
unnamed: D75.1 (K), SW76.2
unnamed: D76.1 (K), SW77.2
unnamed: D77.1 (K), SW78.2
unnamed: D78.1 (K), SW79.2
unnamed: D79.1 (K), SW80.2
unnamed: D80.1 (K), SW81.2
unnamed: D81.1 (K), SW82.2
unnamed: D82.1 (K), SW83.2
unnamed: D83.1 (K), SW84.2
unnamed: D84.1 (K), SW85.2

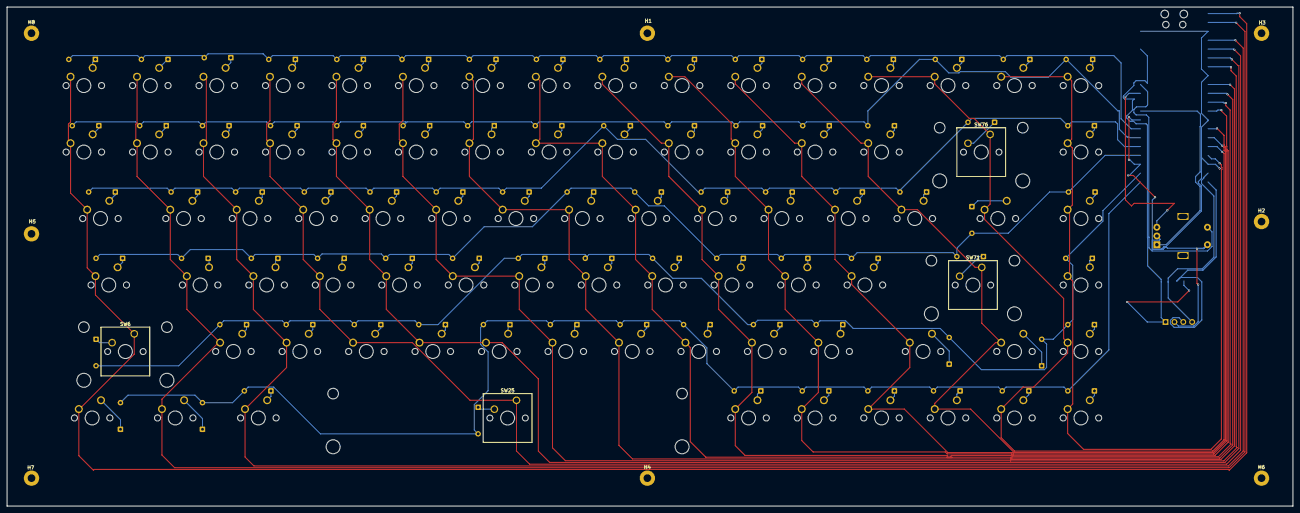
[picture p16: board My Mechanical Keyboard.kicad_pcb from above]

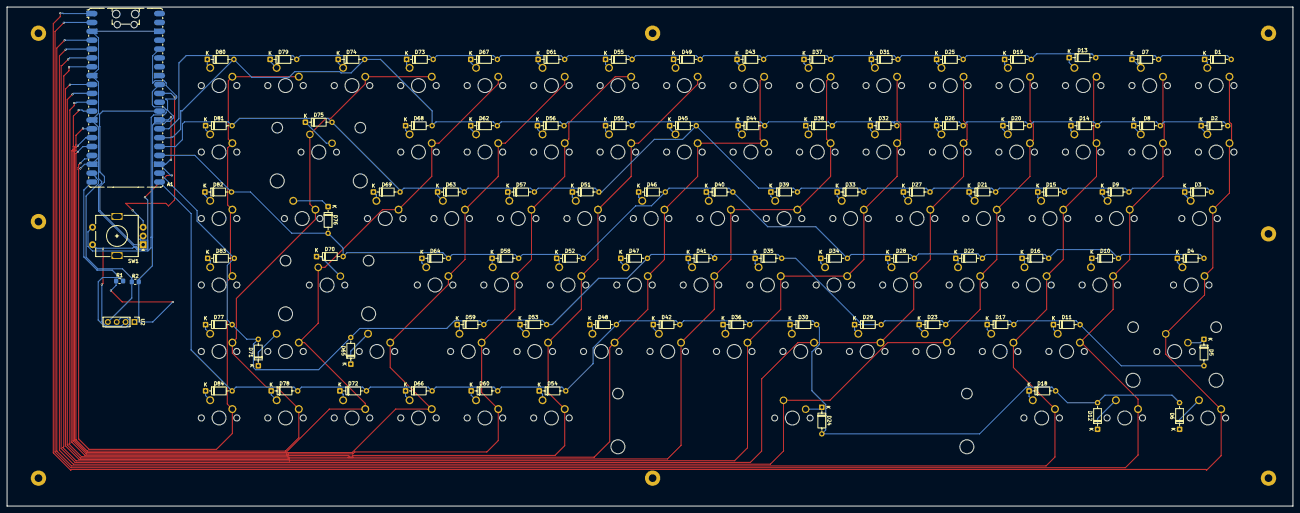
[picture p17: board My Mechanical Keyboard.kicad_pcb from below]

Board: 2 copper layers, 368.5 x 143.0 mm, 181 parts (89 on the bottom side), 111 nets.

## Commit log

2026-10-03 Initial commit of mechanical keyboard project
    [1.25_r1.step, 1.25u_r2.step, 1.25u_r3.step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]
2026-10-03 chore: clean up repo tracking filters and purge backup/cache files
    [My Mechanical Keyboard.kicad_pcb, My Mechanical Keyboard.kicad_sch]
2026-10-03 Added BOM
    [BOM.csv]
